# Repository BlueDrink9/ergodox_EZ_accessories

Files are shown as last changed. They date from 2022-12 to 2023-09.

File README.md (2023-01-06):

# Ergodox EZ 3d accessories for 3d printing

Of general use might be the `ergodox_ez_outline.scad`, which contains a bunch of variables and an outline of the base of the Ergodox-EZ that other users may wish to import in order to get the measurements right for their own projects.
Not guaranteed to be 100% accurate, but were measured from a semi-official Ergodox-EZ 3D model so should be pretty close. For all of my prints I have found them to be spot on.

Examples of the main meshes of interest can be previewed on Github by clicking on them. (In the exported meshes folder - no guarantee they are the latest version, only included for easy previewing).

There is also a slice folder with my Cura slicing settings. Choices made may be for esoteric reasons like speed, so use as a guide at best.

## Accessories

### Vertical bracket mount

Totally rethinking ultimate keyboard ergonomics. Obtain a fully neutral shoulder angle, at minimal expense.

Designed to slide onto an L bracket, allowing the keyboard to be used with your arms hanging fully vertically down (most useful when standing).
Example images to come later, once prototyping is complete.

Prints in 3 pieces: tops, left bottom, right bottom. Joints without glue, easily disassembled.

#### Slice notes

Benefits from high infill to increase ridgidity. I went with 60% in gyroid patten. Also recommend thick (1.5mm) walls. It actually isn't that expensive time-wise because that means most of the walls don't have infill but can just be done back and forth.

### Upright bracket

A less radical design, intended to enable extreme tilting of 60º+.
Redesign with much better dimensional accuracy of https://www.thingiverse.com/thing:3207945 and https://www.thingiverse.com/thing:2748084.
My redesign is more customisable (you can change the angle, wall and base thicknesses, wall height), which also gives it much-needed strength compared to the other designs.

Intended to be held on the desk or armrest with some variant of [this clamp](https://www.thingiverse.com/thing:3075868), although the sockets for the clamp can be disabled with a parameter.

Again, photo examples are on their way.

#### Slice notes

Needs a decent infill, otherwise the walls may snap. The limiting factor is layer adhesion, so do what you can when slicing to increase it and you should be fine.
Unlike the projects it is based off, it minimises thin extensions that I found were very likely to snap. There are still some parts that are likely to snap, but the mount should still work without them.

I recommend slicing this sideways (so that it kinda looks like a Y from above), so that the parts that stick out are all printed with a single layer in the direction they stick out. Otherwise, layer adhesion is the only thing stopping them from snapping, and it isn't likely to be as strong.

## Build

Probably need to install [BOSL2](https://github.com/revarbat/BOSL2)

Then open the .scad files in OpenSCAD.

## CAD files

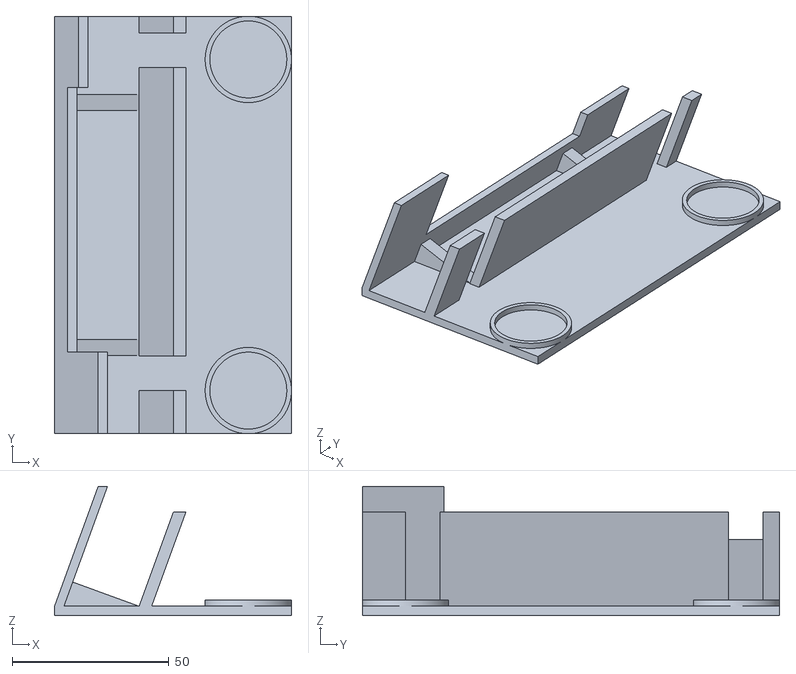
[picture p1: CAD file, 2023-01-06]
exported_meshes/Ergodox-EZ upright bracket.stl
75.5 x 133.0 x 41.2

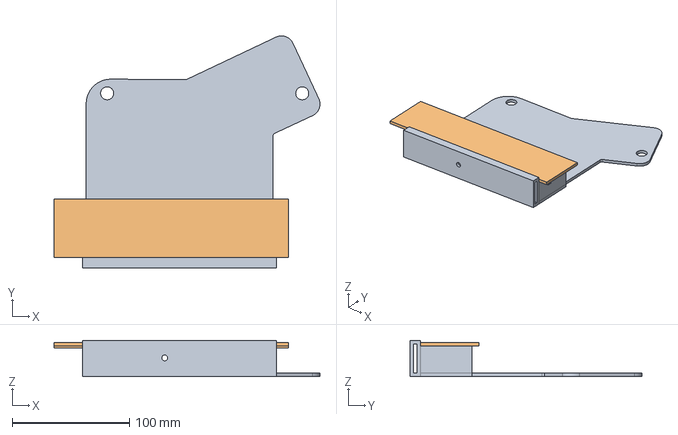
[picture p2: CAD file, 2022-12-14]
freecad/mount_before_redo.FCStd
227.0 x 198.1 x 31.0 mm
Whole mount right hand
Splitter only

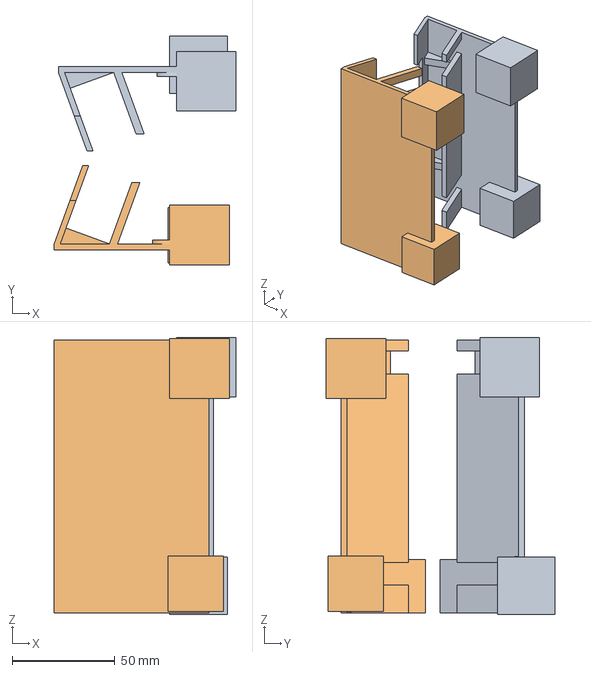
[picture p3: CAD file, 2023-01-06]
slice/ultimaker2+/UM2_Ergodox-EZ upright bracket.3mf
88.6 x 111.8 x 135.0 mm
Ergodox-EZ upright bracket.stl
Ergodox-EZ upright bracket.stl(2)

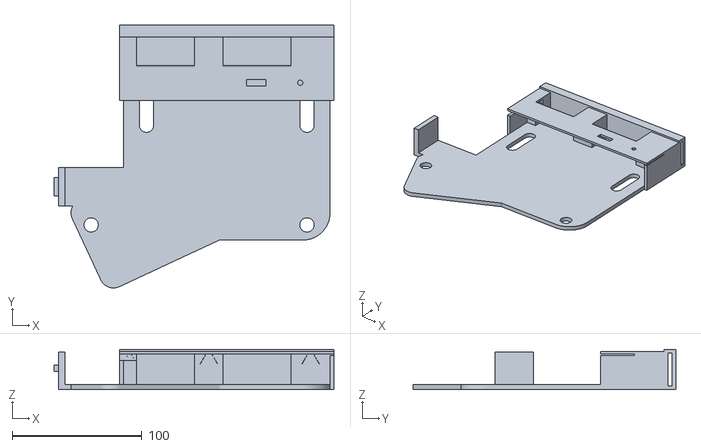
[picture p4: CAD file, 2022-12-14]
exported_meshes/vertical bracket mount.stl
216.0 x 202.8 x 31.1

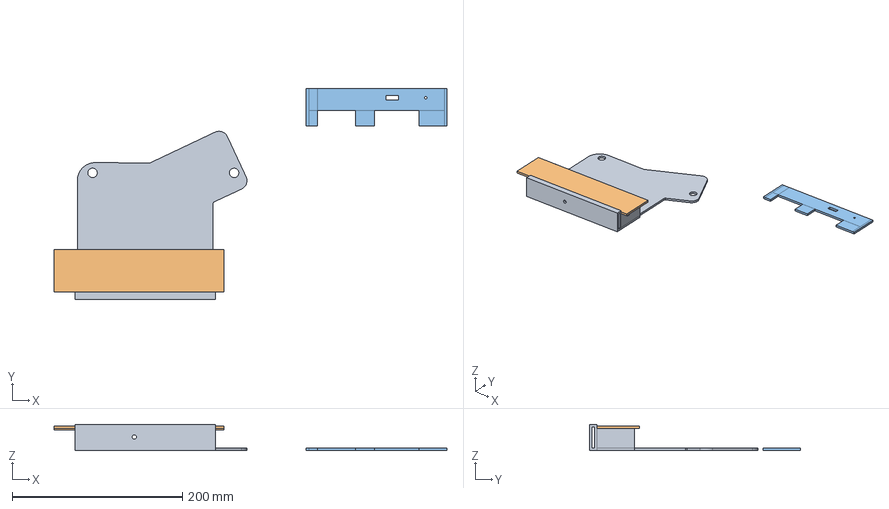
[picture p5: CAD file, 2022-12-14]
freecad/mount.FCStd
462.2 x 248.6 x 31.0 mm
Whole mount right hand
Splitter only
Top half only (Mirror #1)

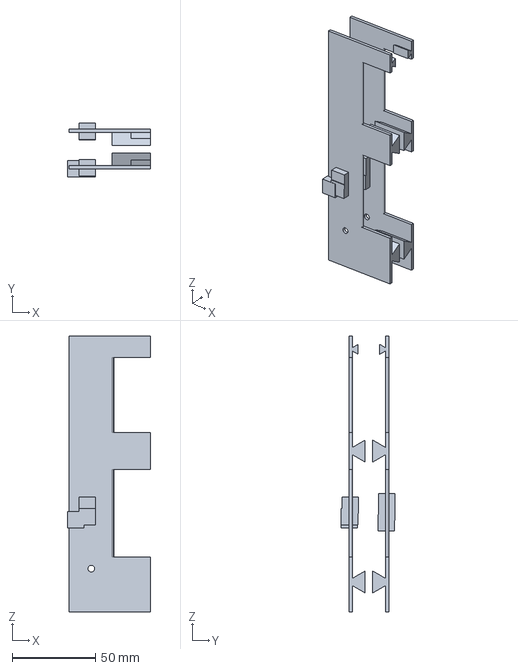
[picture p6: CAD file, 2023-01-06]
slice/ultimaker2+/UM2_mount_tops_lengthwise.3mf
49.7 x 32.5 x 165.5 mm

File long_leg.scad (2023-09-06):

$fs= $preview ? 1 : 0.1;
$fa= $preview ? 12 : 3;
overlap = 0.01;
include <BOSL2/std.scad>

foot_d = 8.2; // Actual measure 8
ankle_d = 6.6; // Actual measure 7
ankle_l = 2;
leg_w = 9;
leg_l = 95; // OEM legs are 45, Thingiverse extended legs are 85.
head_inner_d = 7;
// Head has 2 parts: a thinner part that interfaces with the hole on the
// ergodox, which needs to be within a certain size; and the thicker main
// part of the head, which can be as thick as you want for strength.
head_outer_d = head_inner_d + 6;
head_interface_outer_d = 10.3;
head_interface_h = 0.8;
// Neck is the length between the ergodox and the leg; make this longer to
// put a bigger gap betreen the body and the leg when folded.
// Neck is also where the head narrows for the screw (no reason it
// couldn't be a separate length but this is convenient).
neck_h = 3;
screw_hole_d = 3;

knurl_n_prisms = 40;
knurl_prisms_h = 0.20;
knurl_prisms_w = 0.40;

translate([0,-ankle_l,0]) foot();
leg();
translate([0,leg_l+head_inner_d/2, -leg_w/2 - neck_h]) head();

module foot(){
    // foot
    difference() {
        sphere(d=foot_d);
        translate([-foot_d,0,-foot_d]) cube(foot_d*2);
    }
    // ankle
    rotate([-90,0,0]) linear_extrude(ankle_l) circle(d=ankle_d);
}

module leg(){
    translate([-leg_w/2, 0, -leg_w/2]) cuboid([leg_w, leg_l, leg_w],
    chamfer=1, p1=[0,0,0]);
}

module head(){
    translate([0,0,+neck_h]){
        difference(){
            cylinder(leg_w, d=head_outer_d);
            translate([0, 0, -overlap]) cylinder(999, d=head_inner_d);
        }

        translate([0,0,-neck_h]){
            difference(){
                cylinder(neck_h, d=head_outer_d);
                translate([0, 0, -overlap]) cylinder(999, d=screw_hole_d);
            }
            // interface with dox
            translate([0,0,-head_interface_h]){
                difference(){
                    cylinder(neck_h, d=head_interface_outer_d);
                    translate([0, 0, -overlap]) cylinder(999, d=screw_hole_d);
                }
            }
        }
    }

    // Knurling
    translate([0,0,-head_interface_h+overlap]){
        difference(){
            for(i = [0:knurl_n_prisms-1]) {
                angle = i * 360 / knurl_n_prisms;
                rotate([0, -180, angle+90]) { // +90 to have the base of the
                    prismoid(
                            [knurl_prisms_w,head_interface_outer_d/2-overlap],
                            [0,head_interface_outer_d/2-overlap],
                            h=knurl_prisms_h, anchor=BOTTOM+BACK+CENTER);
                }
            }
            translate([0, 0, -99]) cylinder(999, d=screw_hole_d+1);
        }
    }

}

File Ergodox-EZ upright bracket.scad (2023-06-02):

// Upright mount/bracket for Erdodox EZ, so you can type without pronated wrists. The ultimate tent.
// Designed to slot onto the pinky side of the keyboard.
// This file models the right side. Mirror for left.
// Inspired/based off https://www.thingiverse.com/thing:3207945/comments
// and https://www.thingiverse.com/thing:2748084
include <ergodox_ez_outline.scad>;
use <BOSL2/std.scad>;

overlap = 0.01;

upright_bracket();
module upright_bracket(
        // Inner = the side of the base pointing towards the other keyboard.
        base_inner_width = 50,
        base_outer_width = 0,
        base_thickness = 3,
        wall_inner_thickness = 4,
        wall_outer_thickness = 3.5,
        tilt_angle = 70,
        // How tall the walls are, basically. Back cover is for the outer wall,
        // main wall is the inner wall (on the bottom of the ergodox.
        // 40 mm covers the reset hole. The LED window starts 55mm in
        back_cover_width = 30,
        main_wall_height = 40,
        include_clamp_slot = true,
        // Base rest is what the board sits on when angled.
        // Doesn't need to be very thick.
        base_rest_thickness = 5,
        ){
    // 6.6 mm between edge of board and socket for first key.
    // 7 mm by micrometer.
    low_wall_height = 6.8;
    clamp_diameter = 24.5;
    front_right_key_distance_from_right = 16;
    rightmost_column_bottom_key_distance_from_bottom = 25.7;
    // Distance between the walls gets smaller the larger the angle.
    // We want it to stay the thickness of the board, regardless of angle.
    // Need to move the walls apart to account for that.
    // sin(x) = o/h; h = o/sin(x);
    // 0.8 is fine-tuning for my particular board + tolerances.
    wall_distance_apart = keyboard_height / sin(tilt_angle) - 0.4;

    base();
    if (include_clamp_slot) {
        up(base_thickness-overlap){
            clamp_slot();
            back(main_board_length-clamp_diameter-3) clamp_slot();
        }
    }
    // Skew gets defined as a shift x units across for every 1 unit up.
    // So can be modelled as a right triangle, with desired angle at base,
    // 1 as height and skew as adjacent side.
    // tan(x) = o/a; a = o/tan(x)
    skew = 1/tan(tilt_angle);
    up(base_thickness-overlap) {
            skew(sxz=skew){
            color("blue") right(wall_distance_apart) inner_wall();
            color("green") left(wall_outer_thickness) outer_wall();
        }
    }

    color("purple") translate([0, 0, base_thickness-overlap]){
        // Offset by 25 to put closer to board middle, rather than the ends
        // where the board has rounded corners.
        back(base_rest_thickness + 25) base_rest();
        back(main_board_length - 25) base_rest();
    }

    module base(){
        // Outer base + base under outer wall
        outer_width = base_outer_width + wall_outer_thickness;
        left(outer_width)
            cube([outer_width,
                    main_board_length,
                    base_thickness]);
        // Inner base + base under keyboard
        cube([
                keyboard_height + base_inner_width,
                main_board_length,
                base_thickness]);
    }


    module outer_wall(){
        // Extra adjustment to keep wall off keys
        wall_off_keys_adjustment = 1.5;
        // This wall isn't actually going to reach up the full distance,
        // because of the angle. So can afford to add a bit more length to it.
        // That is calculated as the height correction factor. Treats it like a
        // right angle triangle, where opposite side is the width of the kb
        // bottom and correction length is the adjacent side. Angle is from
        // bottom left. tan(x) = o/a, a = o/tan(x)
        height_correction_factor = (keyboard_height) / tan(tilt_angle);

        // Back cover
        coverable_part_of_back_length = 26;
        cube([
                wall_outer_thickness,
                coverable_part_of_back_length,
                back_cover_width + height_correction_factor
        ]);

        // front corner cover -- avoid getting in the way of the keys
        // Subtract a little to ensure it isn't overlapping with keys
        // and jamming them.
        front_cover_width = front_right_key_distance_from_right +
            height_correction_factor - wall_off_keys_adjustment;
        front_cover_length = rightmost_column_bottom_key_distance_from_bottom - 3;

        back(main_board_length - front_cover_length) cube([
                wall_outer_thickness,
                front_cover_length,
                front_cover_width
        ]);

        // low_wall
        cube([
                wall_outer_thickness,
                main_board_length,
                low_wall_height +
                height_correction_factor -
                wall_off_keys_adjustment
        ]);
    }

    module inner_wall(){
        difference(){
            cube([wall_inner_thickness, main_board_length, main_wall_height]);
            feet_gaps();
        }
        module feet_gaps(){
            for (y = [
                feet_front_dist_from_back_edge,
                feet_back_dist_from_back_edge,
            ]){
                back = y - foot_radius;
                translate([-overlap, back, overlap]) cube([
                        wall_inner_thickness+2*overlap,
                        foot_radius*2,
                        main_wall_height,
                ]);
            }
        }
    }

    module clamp_slot(){
        outer_clamp_diameter = clamp_diameter + 3;
        translate([
                keyboard_height + base_inner_width - outer_clamp_diameter/2,
                outer_clamp_diameter/2,
                0]
        ){
            difference(){
                cylinder(d=outer_clamp_diameter, h=2);
                cylinder(d=clamp_diameter, h=2+overlap);
            }
        }
    }

    module base_rest(){
        angle_against_inner_wall = 180 - tilt_angle - 90;
        prism_height = sin(angle_against_inner_wall) * keyboard_height;
        prism_peak_x = cos(angle_against_inner_wall) * keyboard_height;
        rotate([90,0,0]) linear_extrude(base_rest_thickness)
            polygon([
                    [0,0],
                    [wall_distance_apart, 0],
                    [wall_distance_apart - prism_peak_x, prism_height],

            ]);

        /* prismoid(size1=[keyboard_height, base_rest_thickness], size2=[0, base_rest_thickness], h=height_correction_factor); */
    }

}

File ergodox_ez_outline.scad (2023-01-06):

$fa=1;
$fs=0.4;
// Orientations are designed for the right hand keyboard.
// Looking at it straight and flat on a desk with the thumb cluster closest to you, and the LEDs furthest from you.
// The back is the LED cluster end.
// The height is from the desk up.
// The width is from left to right.
// x = width, y = length, z = height
// Origin is at front right corner of the keyboard

overlap = 0.01;
board_width_back = 159.5;
main_board_length = 133;
// Not used, but useful for importing
keyboard_height = 22.5;

front_right_board_corner_radius = 42.14/2;
back_right_board_corner_radius = 12.45;
// thumb_cluster_corner_radius = 21.8;
thumb_cluster_corner_radius = 10.92;
thumb_cluster_angle_away_from_left_side = 115;
// Far left edge
thumb_cluster_width = 73.7;
// front-most edge
thumb_cluster_length = 95.8;
thumb_cluster_right_inflection_len_from_right_side = 85.5;
// Busting back out the high school trig, wow.
thumb_cluster_left_inflection_distance_from_back = main_board_length - (cos(180-thumb_cluster_angle_away_from_left_side) * thumb_cluster_width);

back_legs_distance_from_back = 44;

foot_radius = 5.5;
// the back 2 feet share position on Y with one-another, as do the front 2.
// the right two feet share their X position.
// Distance is to center of foot radius
feet_back_dist_from_back_edge = 19.2;
feet_front_dist_from_back_edge = 122.1;
feet_right_dist_from_left_edge = 141.7;
foot_back_left_dist_from_left_edge = 17.9;
// Thumb cluster foot
foot_front_left_dist_from_left_edge = -24.8;

module ergodox_outline(square_off_backs=false){

    module board_base(){
        main_base();
        // Thumb cluster
        translate([board_width_back - thumb_cluster_right_inflection_len_from_right_side, -0,0]){
            rotate([0,0,thumb_cluster_angle_away_from_left_side]){
                thumb_cluster();
            }
        }

        module thumb_cluster(){
            // Thumb cluster
            hull(){
                // rounded end
                translate([thumb_cluster_corner_radius,thumb_cluster_length-thumb_cluster_corner_radius,0]){
                    circle(r=thumb_cluster_corner_radius);
                    translate([thumb_cluster_width-2*thumb_cluster_corner_radius,0]){
                        circle(r=thumb_cluster_corner_radius);
                    }
                }
                // Main part of cluster
                translate([0, 0, 0]){
                    square([thumb_cluster_width,
                            thumb_cluster_length-thumb_cluster_corner_radius]);
                }
            }
        }

        module main_base(){
            hull(){
                // fronts - one circle is irrelevant, hidden within the thumb
                // cluster - but something needs to be there to finish the hull.
                for (trans_x = [board_width_back - front_right_board_corner_radius,
                        front_right_board_corner_radius]){
                    translate([trans_x, front_right_board_corner_radius, 0]){
                        circle(r=front_right_board_corner_radius);
                    }
                }
                // backs
                for (trans_x = [board_width_back - back_right_board_corner_radius,
                        back_right_board_corner_radius]){
                    translate([trans_x, main_board_length  - back_right_board_corner_radius, 0]){
                        if(square_off_backs){
                            // For if you are adding something else to the
                            // back (eg a bracket)
                            translate([-back_right_board_corner_radius, 0, 0])
                                square([
                                    back_right_board_corner_radius*2,
                                    back_right_board_corner_radius*2]);
                        }else{
                            circle(r=back_right_board_corner_radius);
                        }
                    }
                }
            }
        }
    }

    module foot_holes(){
        backs = [
            // back left
            [foot_back_left_dist_from_left_edge, feet_back_dist_from_back_edge],
            // back right
            [feet_right_dist_from_left_edge, feet_back_dist_from_back_edge]
        ];
        fronts = [
            // front left/thumb cluster
            [foot_front_left_dist_from_left_edge, feet_front_dist_from_back_edge],
            // front right
            [feet_right_dist_from_left_edge, feet_front_dist_from_back_edge]
        ];
        positions = concat(backs, fronts);
        for(position = positions){
            translate([
                    position.x,
                    main_board_length - position.y,
                    -overlap
            ]){
                circle(r=foot_radius);
            }
        }

    }

    // Board with gaps for feet
    difference(){
        board_base();
        foot_holes();
    }
}

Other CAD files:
slice/ultimaker2+/UM2_bottom right.3mf
slice/ultimaker2+/UM2_mount_tops_sideways.3mf
tapered_dovetail.scad
vertical bracket mount.scad

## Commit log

2022-11-24 Add dimensions and create bracket tunnel
    [vertical bracket mount.scad]
2022-11-25 Split out outline; position feet
    [ergodox_ez_outline.scad]
2022-11-25 Fix thumb cluster position
    [ergodox_ez_outline.scad]
2022-11-25 Refactor out ergodox outline
    [vertical bracket mount.scad]
2022-11-26 Finish bracket as previous
    [vertical bracket mount.scad]
2022-11-26 Tidy up modules
    [vertical bracket mount.scad]
2022-11-29 DRY foot holes
    [ergodox_ez_outline.scad]
2022-11-29 Round edges of outline
    [ergodox_ez_outline.scad]
2022-11-29 Cleaner looping for feet holes
    [ergodox_ez_outline.scad]
2022-11-29 Extend top feet holes
    [ergodox_ez_outline.scad, vertical bracket mount.scad]
2022-11-30 Separate outline and bracket variables
    [ergodox_ez_outline.scad, vertical bracket mount.scad]
2022-11-30 Convert outline to 2D
    [ergodox_ez_outline.scad, vertical bracket mount.scad]
2022-11-30 Add brace against vertical
    [ergodox_ez_outline.scad, vertical bracket mount.scad]
2022-12-01 Round inner cord edge
    [vertical bracket mount.scad]
2022-12-01 Rename top and bottom to back and front
    In line with convention
    [ergodox_ez_outline.scad, vertical bracket mount.scad]
2022-12-01 Cut out channel for cord
    [vertical bracket mount.scad]
2022-12-01 Remove cord channel
    Won't actually be useful at that angle
    [vertical bracket mount.scad]
2022-12-01 Restore a better version of cord channel
    [vertical bracket mount.scad]
2022-12-02 Simplify translation of top cover plate diff --git a/vertical bracket mount.scad b/vertical bracket mount.scad index 4c146a2..b2a486e 100644 --- a/vertical bracket mount.scad +++ b/vertical bracket m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
    module top_coverplate(){
    - translate ([
    - -wall_thickness,
    - -coverable_part_of_back_length + 2*overlap,
    - wall_height + base_thickness - overlap,
    - ]){
    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
    [vertical bracket mount.scad]
2022-12-02 Add in dovetail joins
    [tapered_dovetail.scad, vertical bracket mount.scad]
2022-12-02 Add gaps for teeth to go
    [tapered_dovetail.scad, vertical bracket mount.scad]
2022-12-03 Add print sections
    [vertical bracket mount.scad]
2022-12-07 Fix thumb cluster radius
    [ergodox_ez_outline.scad]
2022-12-07 Move build instructions to top
    [vertical bracket mount.scad]
2022-12-07 Remove brace, resize for ultimaker 2+
    [vertical bracket mount.scad]
2022-12-11 Bits for printing/slicing
    [vertical bracket mount.scad]
2022-12-11 Put height in outline
    [ergodox_ez_outline.scad, vertical bracket mount.scad]
2022-12-14 Add upright bracket with example
    [Ergodox-EZ upright bracket.scad, Ergodox-EZ upright bracket.stl]
2022-12-14 Add cura slices for top and bottom
    [UM2_mount_tops_sideways.3mf, bottom right.3mf]
2022-12-14 Add old freecad files as well
    [mount.FCStd, mount_before_redo.FCStd]
2022-12-14 Slice upright mount
    [Ergodox-EZ upright bracket.scad, UM2_Ergodox-EZ upright bracket.3mf, vertical bracket mount.scad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]
2023-01-05 Increase precision of foot positioning
    [ergodox_ez_outline.scad]
2023-01-05 Upright: fix foot positioning, swap walls
    [Ergodox-EZ upright bracket.scad]
2023-01-06 Upright: fix proportions, correct feet positioning,
    account for angle in
    wall height
    [Ergodox-EZ upright bracket.scad, ergodox_ez_outline.scad]
2023-01-06 Add base_rest
    [Ergodox-EZ upright bracket.scad]
2023-01-06 Refactor base rest; remove outer base
    [Ergodox-EZ upright bracket.scad]
2023-01-06 Move rests to middle of board
    Avoids rounded corners of board
    [Ergodox-EZ upright bracket.scad]
2023-01-06 Update slice and meshes
    [Ergodox-EZ upright bracket.stl, UM2_Ergodox-EZ upright bracket.3mf, UM2_bottom right.3mf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]
2023-06-02 Adjust upright bracket to tighten tolerances
    [Ergodox-EZ upright bracket.scad]
2023-09-06 Create ergodox leg shape
    [long_leg.scad]
2023-09-06 Add dimensions
    [long_leg.scad]
2023-09-06 Chamfer leg edges
    [long_leg.scad]
2023-09-06 Add neck interface
    [long_leg.scad]
2023-09-06 Lengthen leg by 1 cm
    [long_leg.scad]
2023-09-06 Add knurling
    [long_leg.scad]
